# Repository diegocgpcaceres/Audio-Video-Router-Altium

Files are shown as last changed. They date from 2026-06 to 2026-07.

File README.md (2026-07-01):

# Audio/Video Router PCB Design

Diseño completo de PCB para un sistema de distribución de audio y video, desarrollado como proyecto integrador de la materia **Diseño Asistido por Computadora (DAC)** de Ingeniería Electrónica.

El proyecto abarca la captura esquemática, diseño de PCB, generación de documentación de fabricación y modelado 3D utilizando Altium Designer.

## Tecnologías y Herramientas

* **Diseño PCB:** Altium Designer
* **Modelado 3D:** Herramientas integradas de Altium Designer
* **Documentación:** BOM (Bill of Materials), planos de fabricación y ensamblado

## Estructura del Repositorio

* `/Preproyecto`: Contiene la propuesta inicial presentada para la materia, descripción del proyecto y link del fabricante.

* `/Entrega Final`: Contiene toda la documentación técnica del proyecto:

  * Archivos fuente de Altium Designer.
  * Informe técnico final.
  * Bill of Materials (BOM).
  * Datasheets de los componentes utilizados.
  * Documentación de fabricación.
  * Modelo 3D del gabinete desarrollado en OnShape.
  * Renderizados finales del PCB y del ensamblado completo.
 
## Características del Proyecto

* PCB de dos capas.
* Más de 200 componentes electrónicos.
* Componentes SMD y Through-Hole.
* Generación automática de BOM.
* Modelado tridimensional del ensamblado final.

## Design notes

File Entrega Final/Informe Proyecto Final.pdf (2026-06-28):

### Proyecto Final: DISTRIB 8x Stereo audio/video distribution router v2.1

MATERIA: Diseño Asistido por Computadora

CURSO: R1051

PROFESOR: Ing. Juan Manuel Perdomo

AYUDANTES: Ing. Cesar Angel Fuoco, Ing. Federico Giorno, Sr. Pedro Vergili

ALUMNO: Diego Cáceres

MAIL: diegocgp@frba.utn.edu.ar

I) Descripción

El DISTRIB 8x Stereo audio/video distribution router v2.1 usa elementos thru-hole y SMD junto a varios circuitos integrados para el manejo de varios tipos de señales (tanto digitales como analógicas, según el fabricante) con el propósito de entregar audio y video.

Para el diseño del PCB se usaron las dos capas permitidas (Bottom Layer y Top Layer) facilitando el diseño de las pistas, aprovechando el uso de los componentes Thru Hole y de vías.
Las dimensiones finales del PCB son 100mm X 135.5mm usando un total de 204 componentes como se detalla en el archivo Excel “R1051-Caceres-PF-BOM” generado por el mismo Altium usando la herramienta Bill Of Materials.
La diferencia entre la cantidad de componentes actual y la presentada en el Pre-Proyecto se debe a la omisión de algunos componentes, como los pulsadores, que entorpecían el diseño del PCB y que el mismo diseñador no usa sobre la placa misma, utilizar tiras de pines hembra que cuentan como unidad, y posiblemente algún fallo al contar los componentes.

El diseño del Gabinete se adaptó a las medidas del PCB conservando el largo original, proporcionado por el diseñador, manteniendo las aperturas necesarias para los puertos de comunicación y alimentación.

II) Diagrama en Bloques

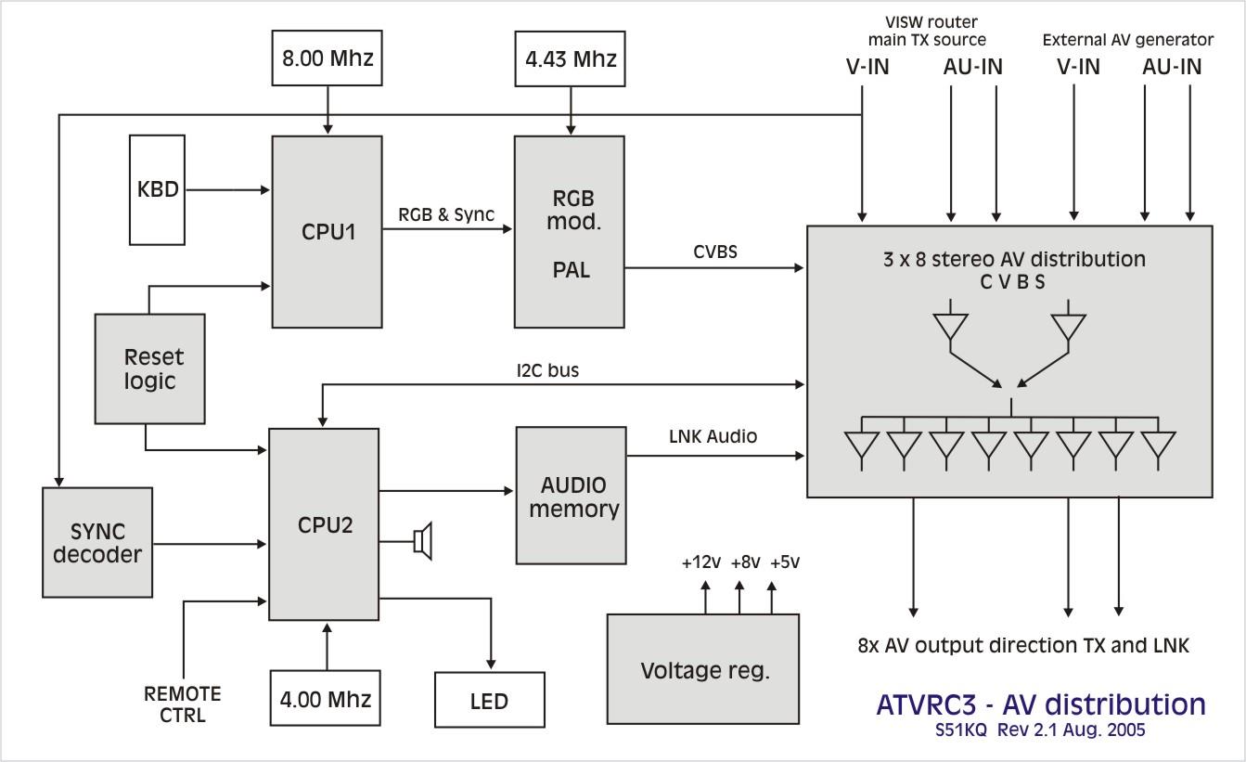
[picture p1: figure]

El diagrama en bloques presentado es el mismo proporcionado por el diseñador, siendo que varios esquemáticos del proyecto reciben su nombre debido al mismo.
En la siguiente tabla se muestra el correspondiente bloque asociado con el o los esquemáticos antes mencionados.
BLOQUES | ESQUEMÁTICOS
Voltage reg. | Power Supply
SYNC decoder | Sync Decoder
Reset logic | Audio_Video Controller
CPU1 | RGB Video Controller
CPU2 | Audio Controller
AUDIO memory | Audio Memory
RGB mod. PAL | RGB to PAL Encoder
3 x 8 stereo AV distribution | Video OUT
Left Channel Audio
Right Channel Audio

III) Diagramas de Esquemáticos

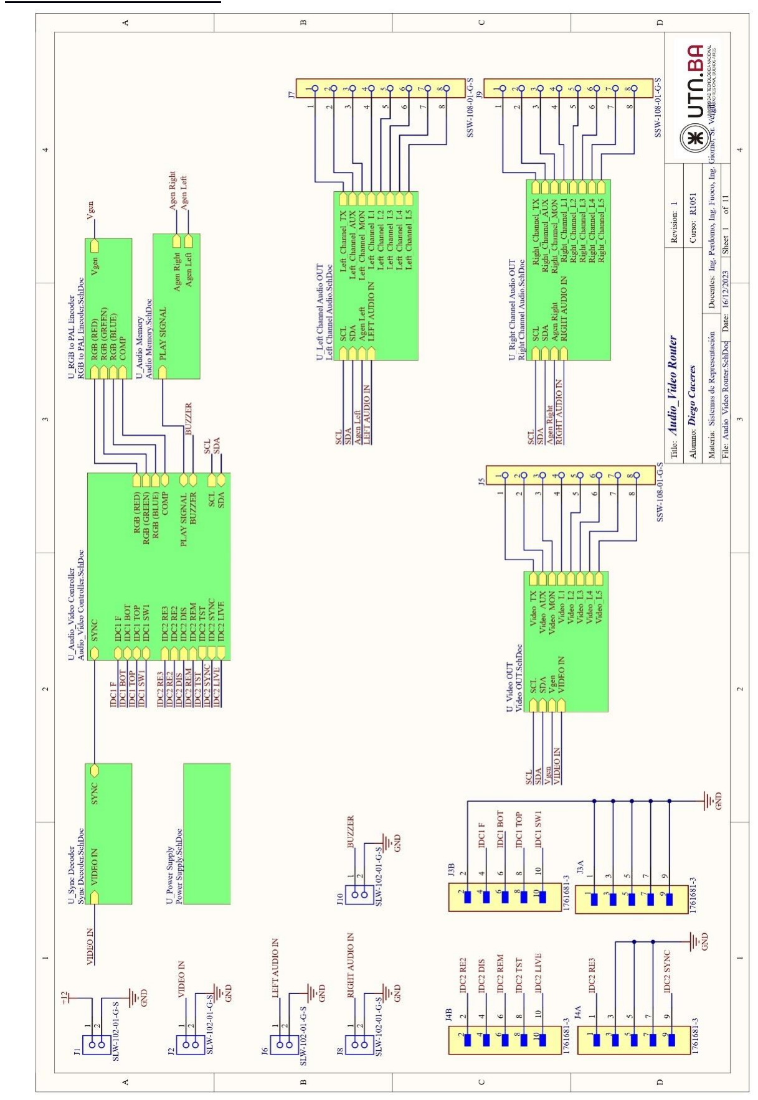
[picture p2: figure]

- Audio_Video Router

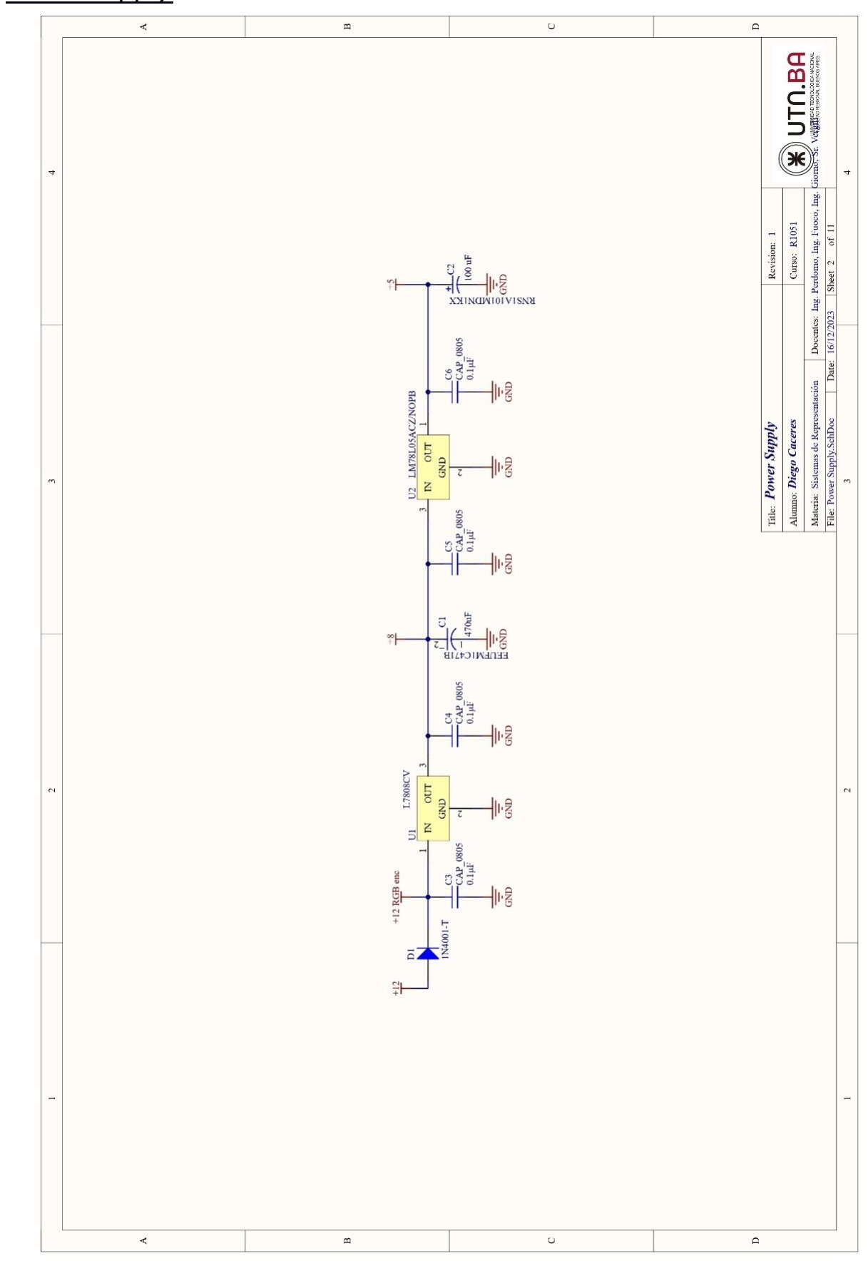
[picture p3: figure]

- Power Supply

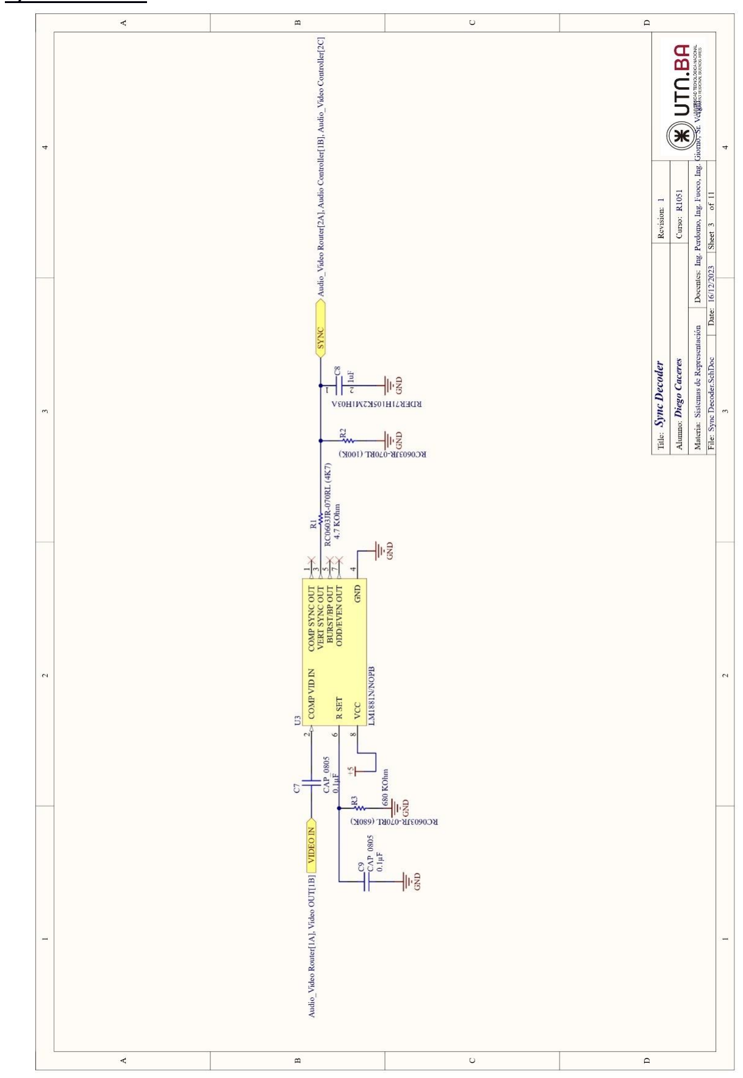
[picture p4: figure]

- Sync Decoder

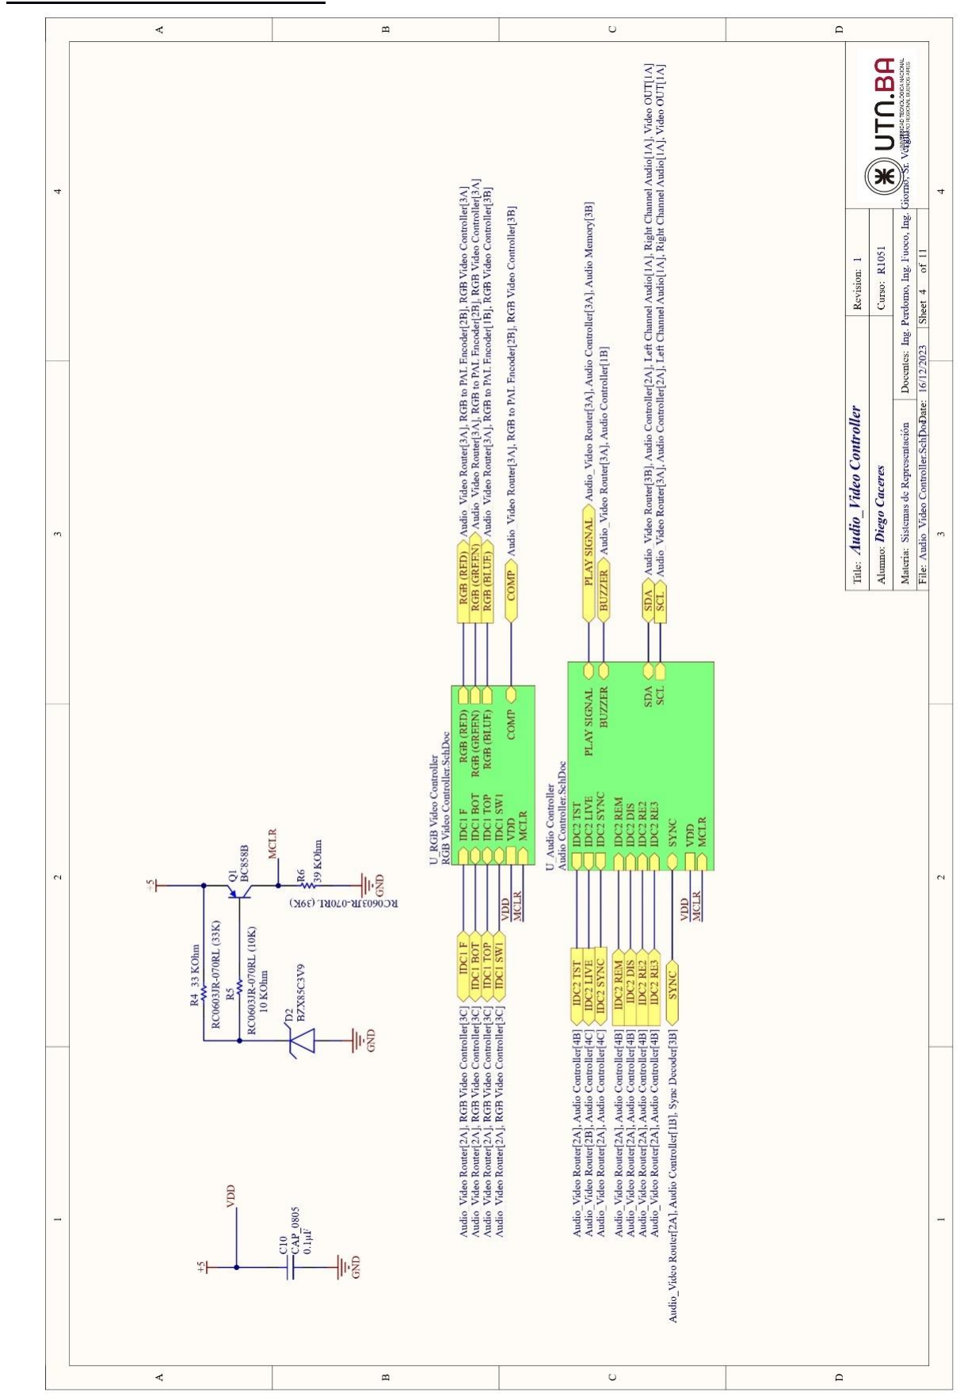
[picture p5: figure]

- Audio_Video Controller

- RGB Video Controller

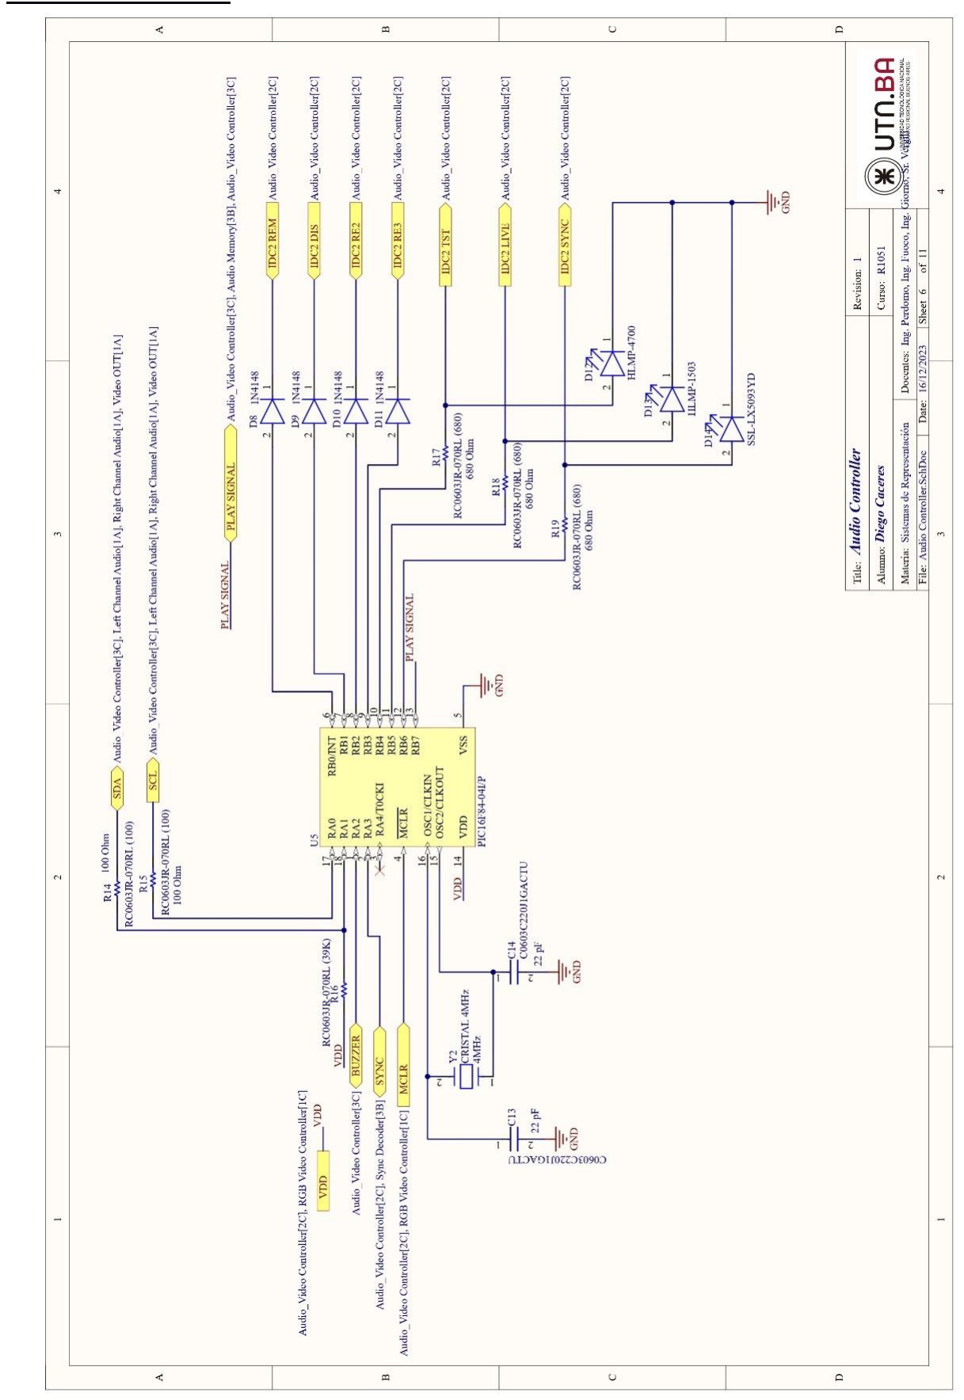
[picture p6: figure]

- Audio Controller

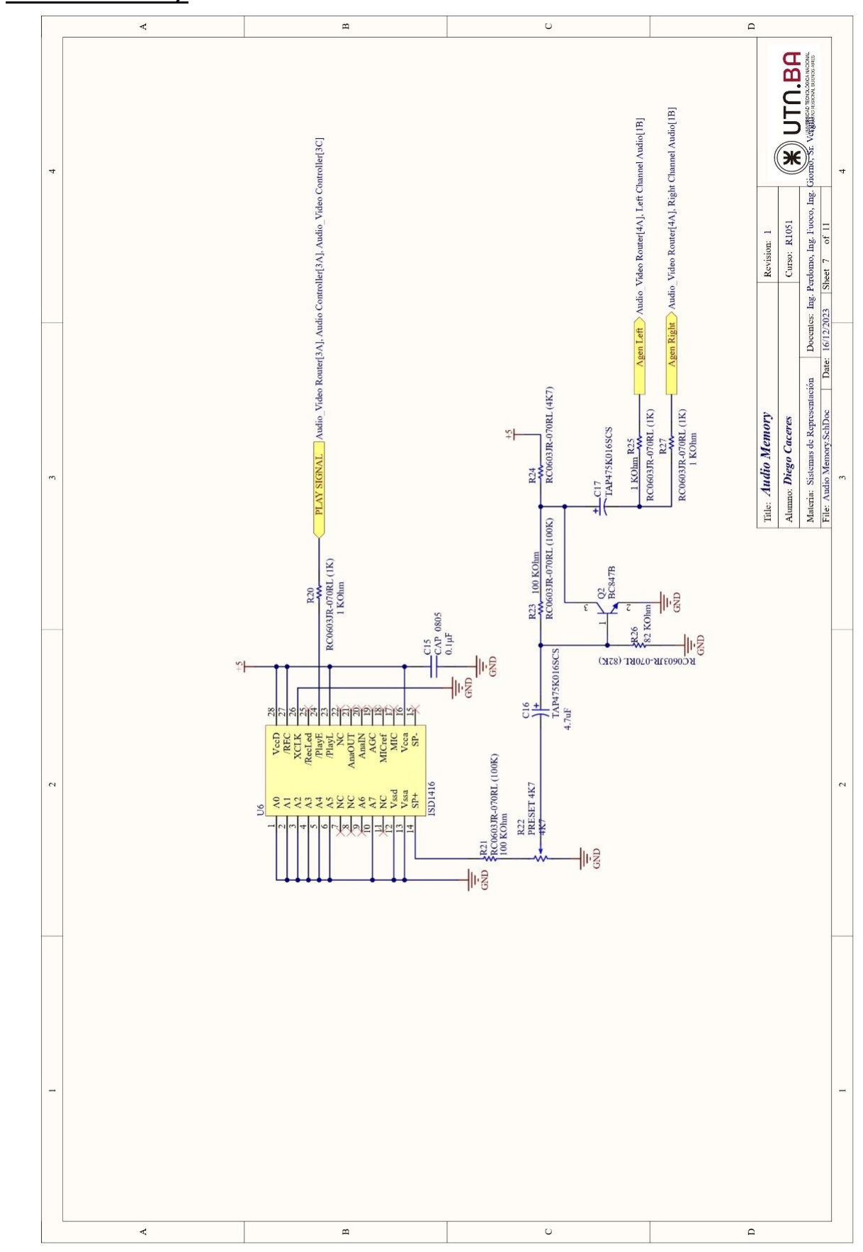
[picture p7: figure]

- Audio Memory

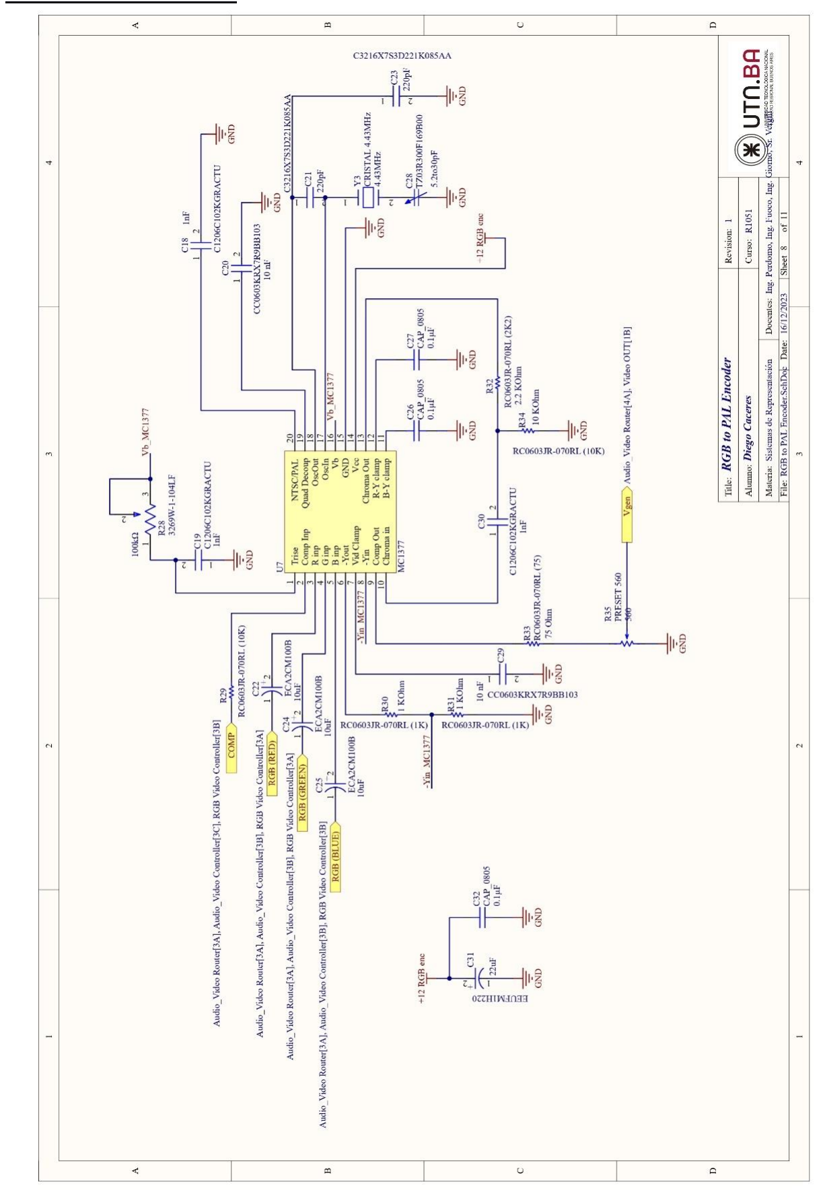
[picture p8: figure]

- RGB to PAL Encoder

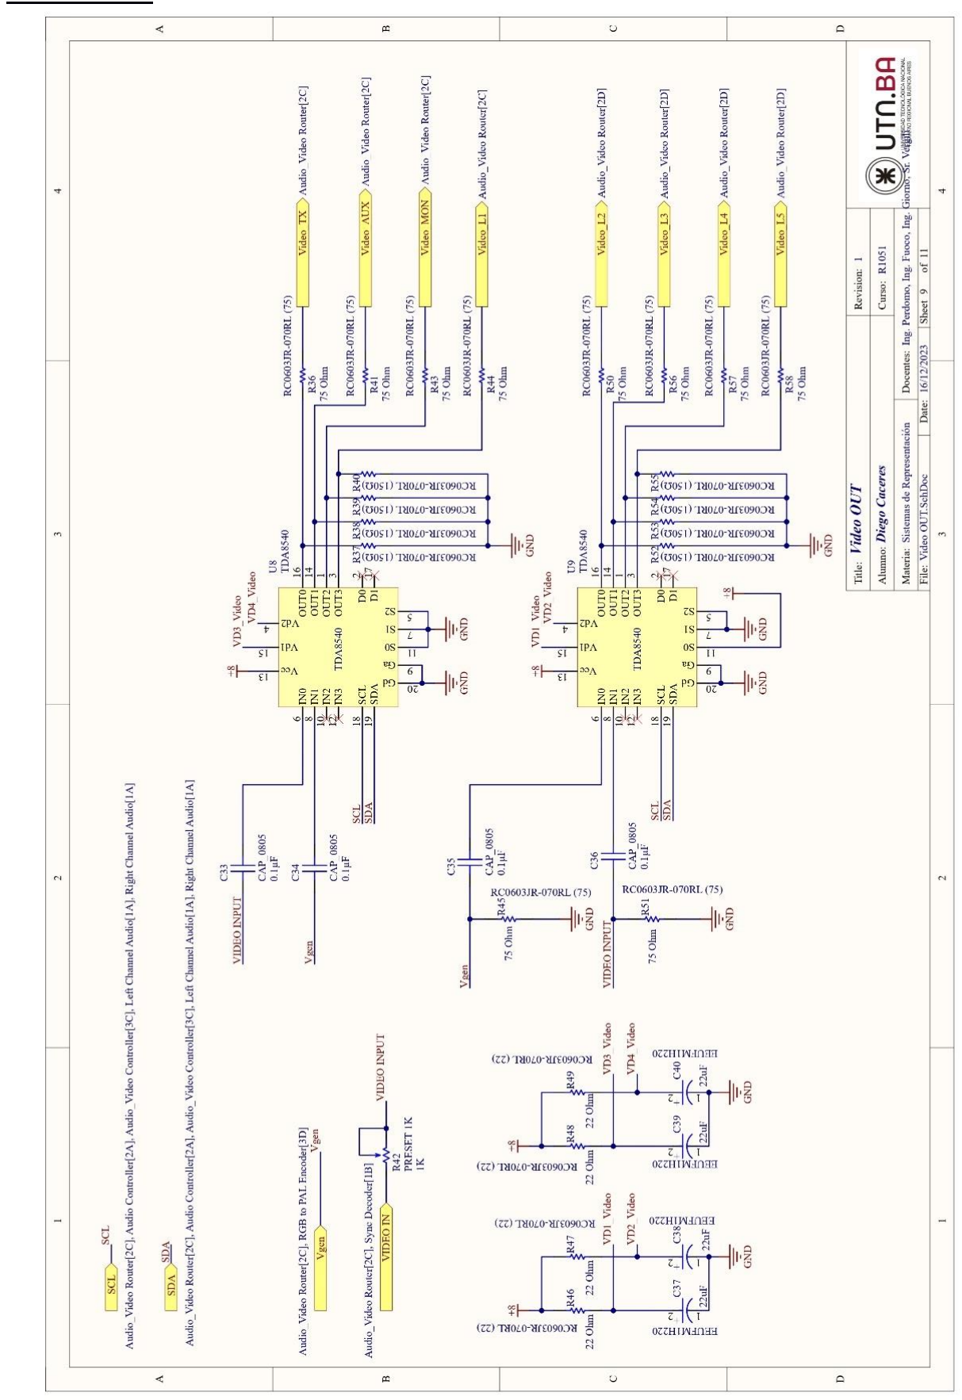
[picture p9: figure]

- Video OUT

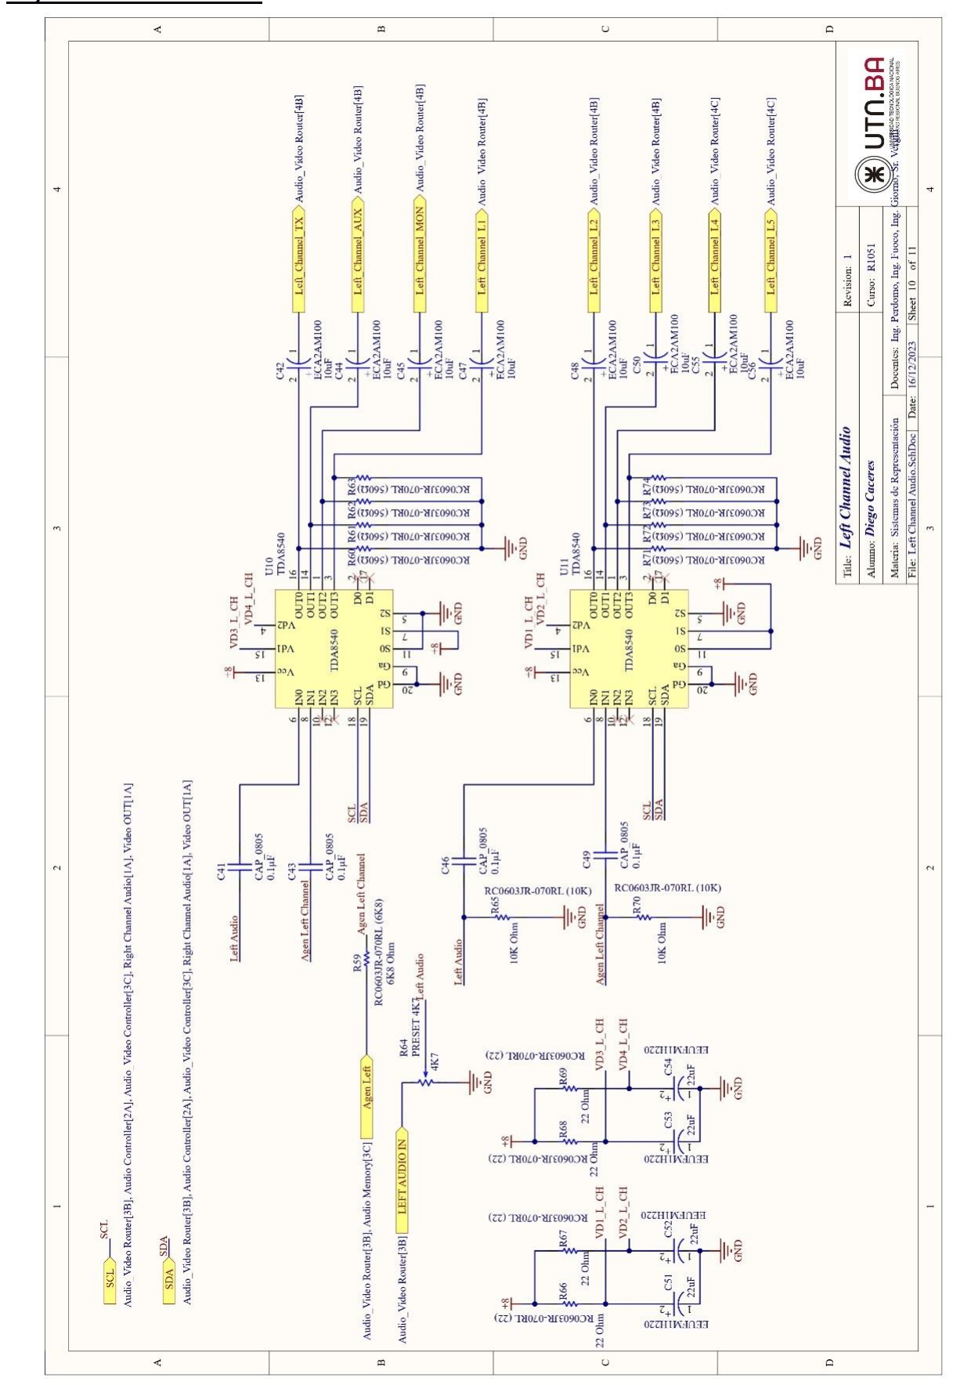
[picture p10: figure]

- Left Channel Audio

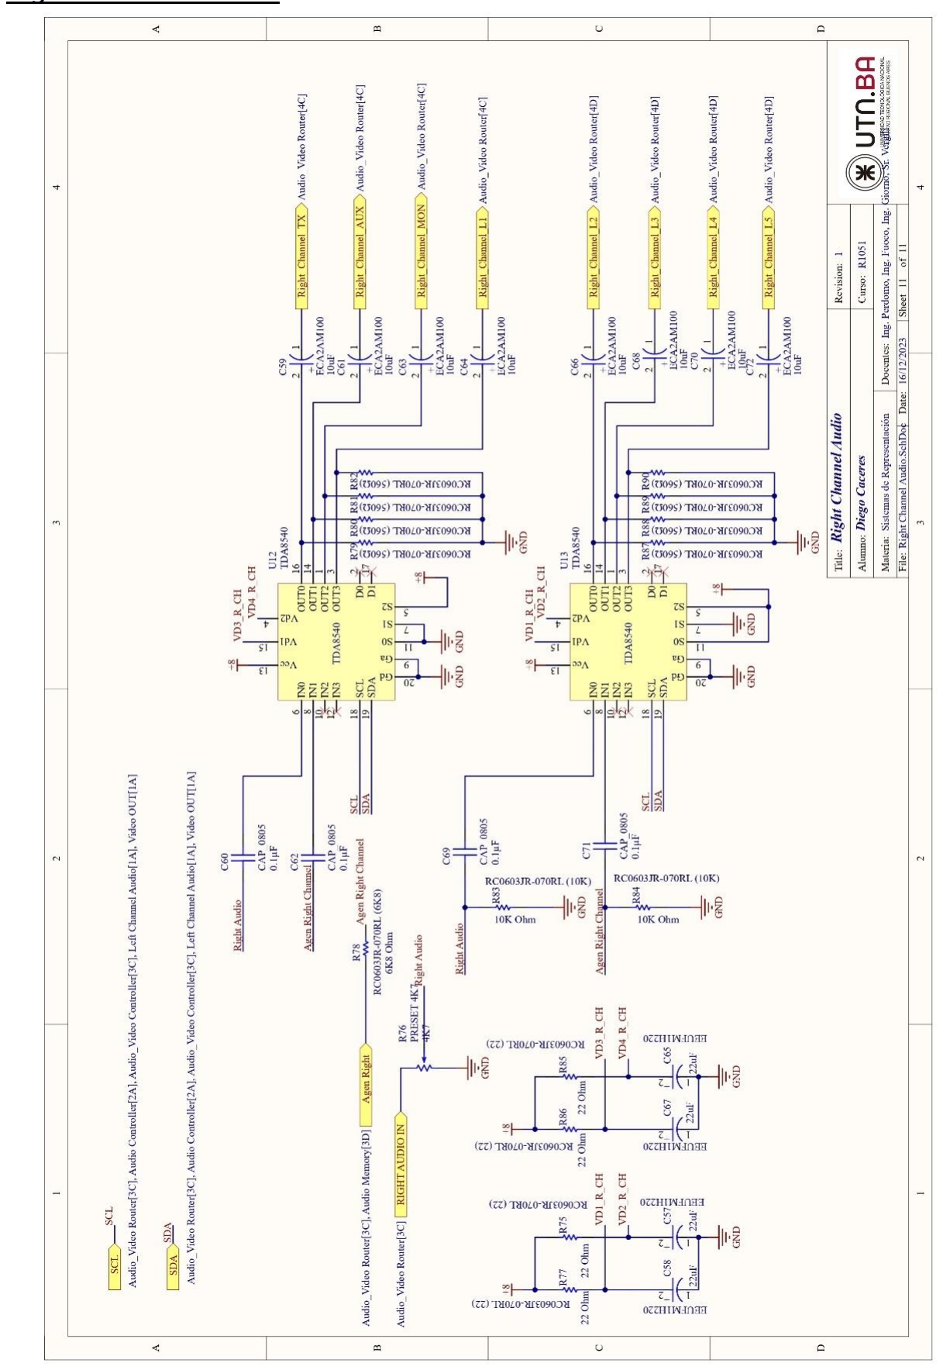
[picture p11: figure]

- Right Channel Audio

IV) Especificaciones Técnicas del PCB

Debido a que el PCB se basa totalmente en el uso de circuitos integrados es de esperar que la corriente no sea elevada.
De las hojas de datos se puede extraer que la corriente máxima que maneja el MC1377 es de 40mA, siendo está la corriente de mayor valor encontrado a lo largo de los datasheets de los integrados.

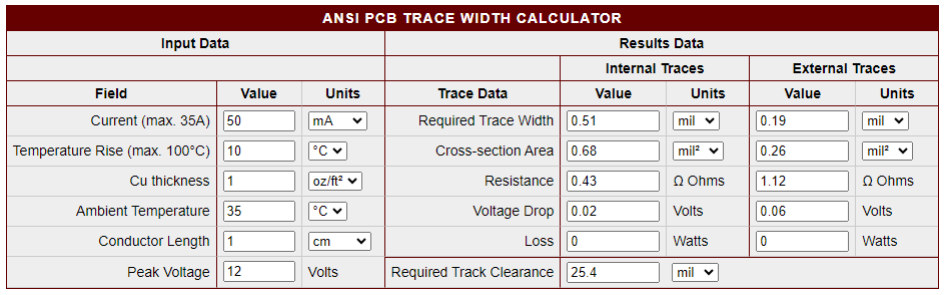
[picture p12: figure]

Para corroborar que la corriente no presenta un problema respecto a la temperatura en el diseño se recurrió a la norma IPC – 2221, entrando con una corriente de 50mA, mayor a la vista anteriormente; por lo que el criterio usado para el diseño del PCB es de 10 MILS

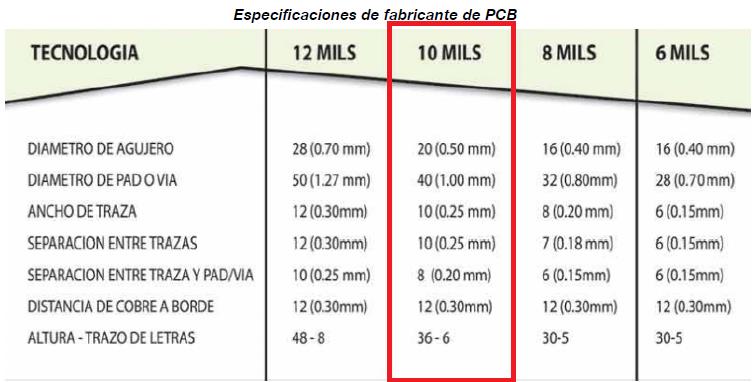
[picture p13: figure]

Que fueron introducidas en el diseño del PCB a través de las Rules que proporciona Altium.

V) Diagrama del PCB

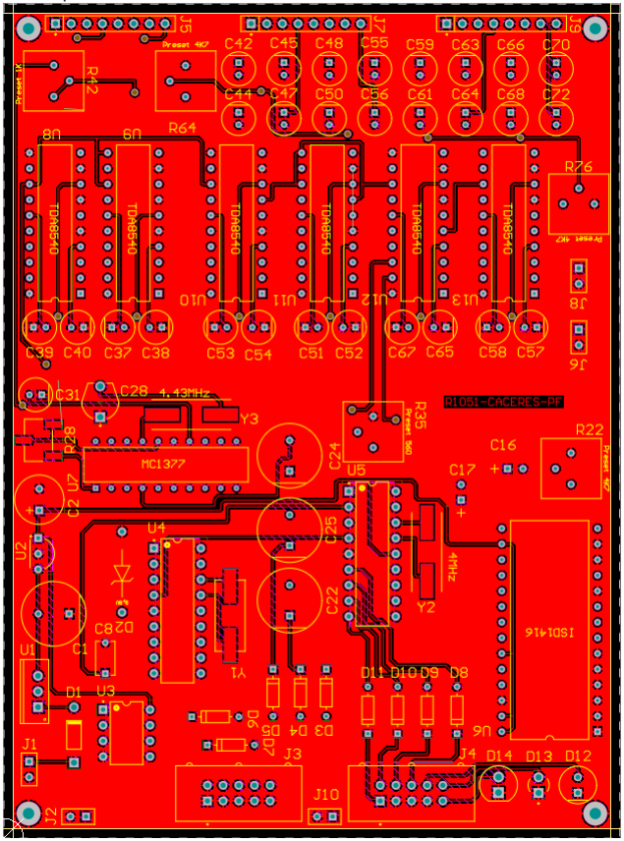
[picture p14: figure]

- Vista Top

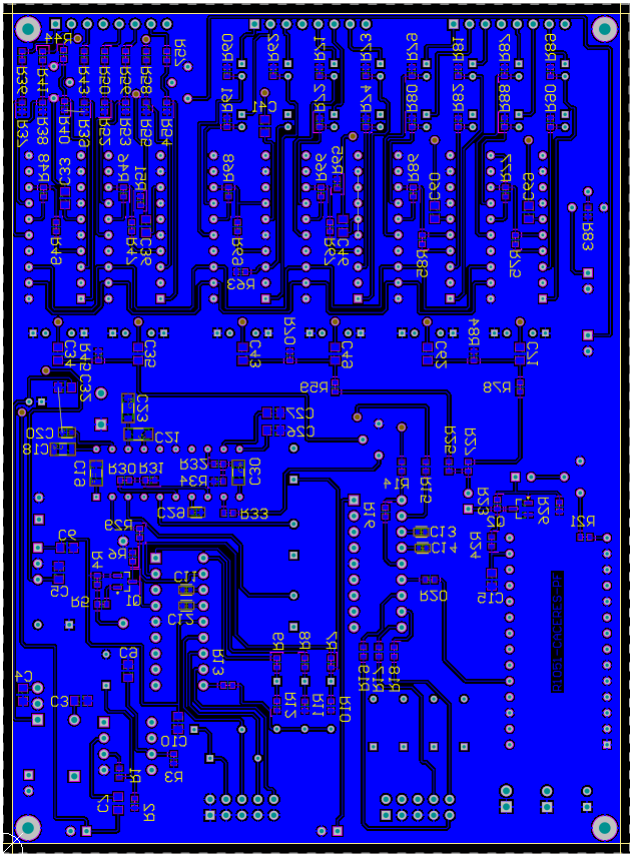
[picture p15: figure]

- Vista Bottom

VI) Render 3D del PCB Completo

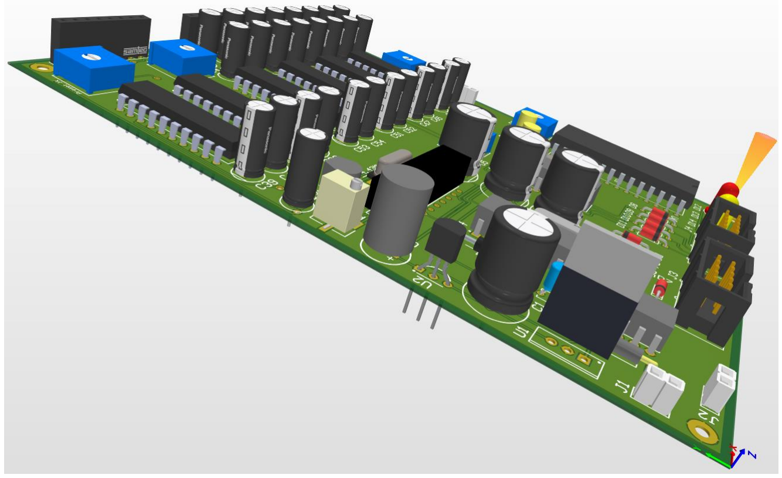
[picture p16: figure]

- Vista Isométrica

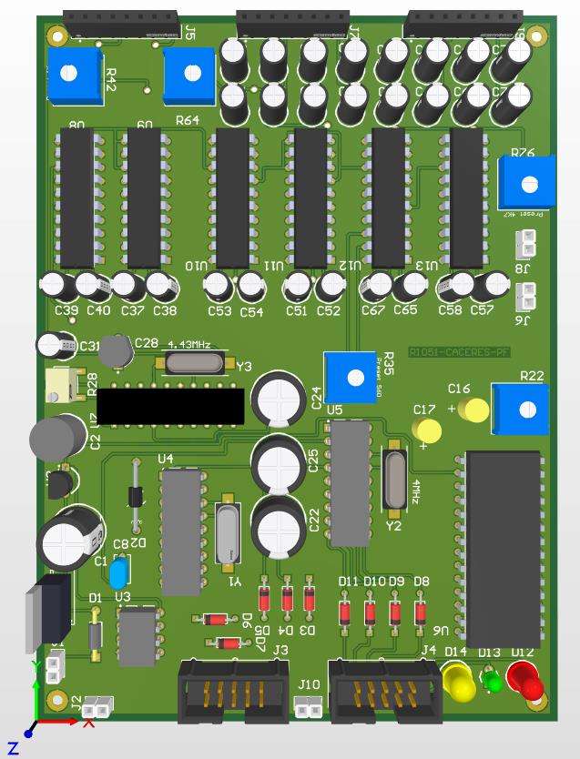
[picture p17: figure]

- Vista Superior

- Vista Inferior

VII)Lista de componentes

La entrega de este documento viene acompañado con el archivo EXCEL “R1051-Caceres-PF-BOM” generado por Altium usando la herramienta Bill Of Materials.
Igualmente se presenta en forma de imagen el contenido de dicho archivo en forma de imagen.

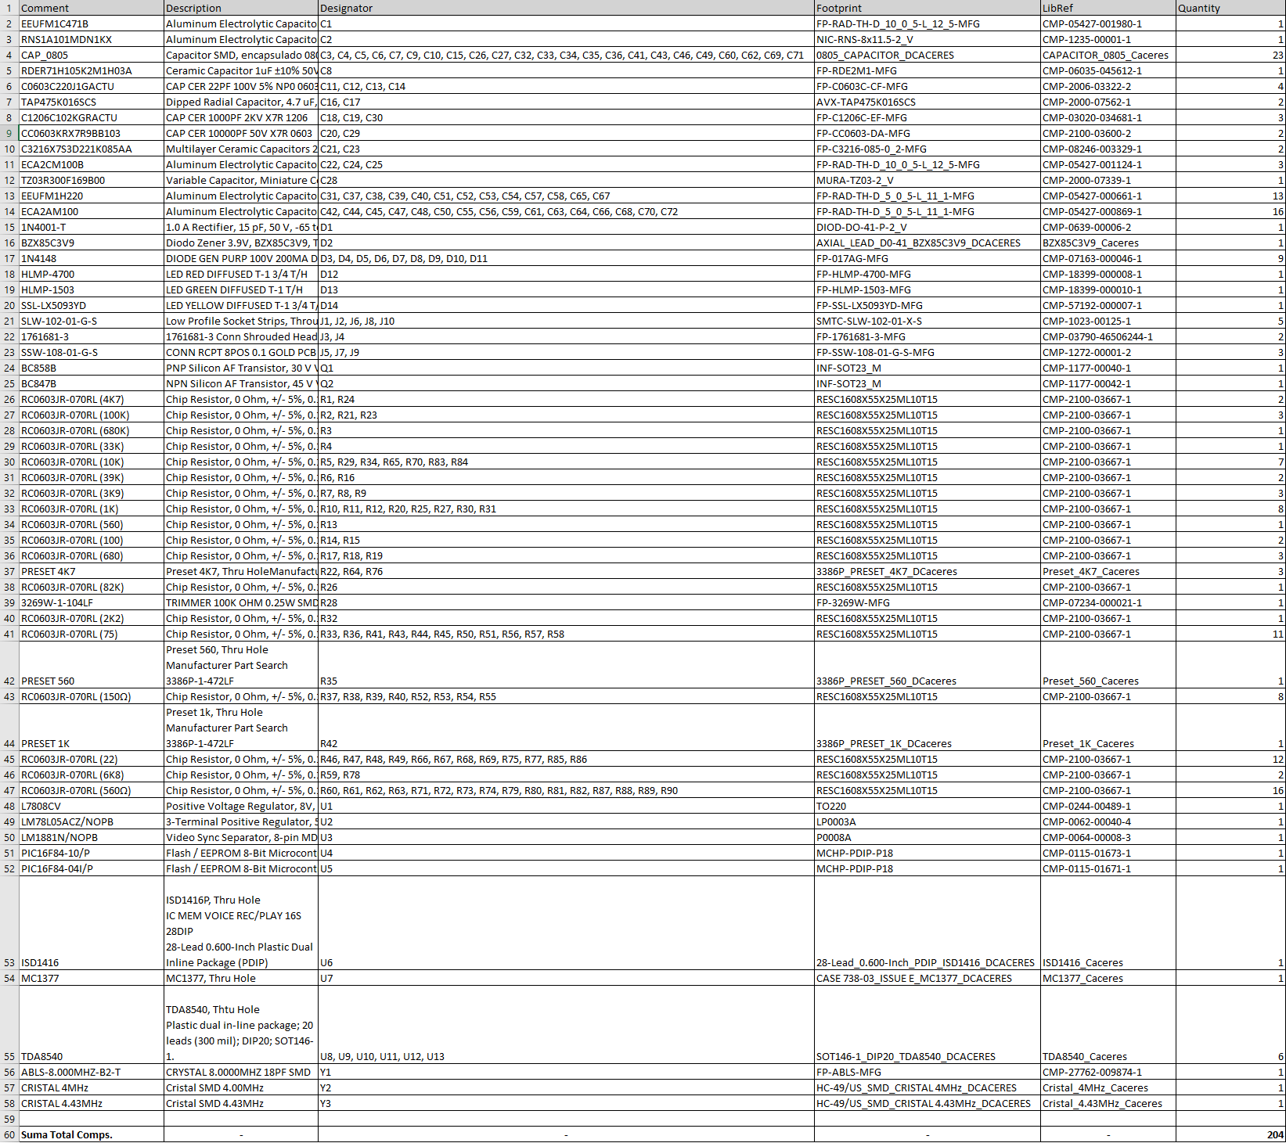
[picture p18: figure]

VIII) Especificaciones Técnicas del Gabinete

Las dimensiones del Gabinete son 200mm X 437 mm x 45mm. El mismo presenta orificios en la parte inferior para asegurar la placa usando tornillos con diámetro de 2mm, cabeza de 4mm y largo no mayor a 24mm.

El Largo del Gabinete es el mismo que el del diseñador manteniendo así las aperturas necesarias para los puertos de comunicación y la alimentación, como se muestra a continuación

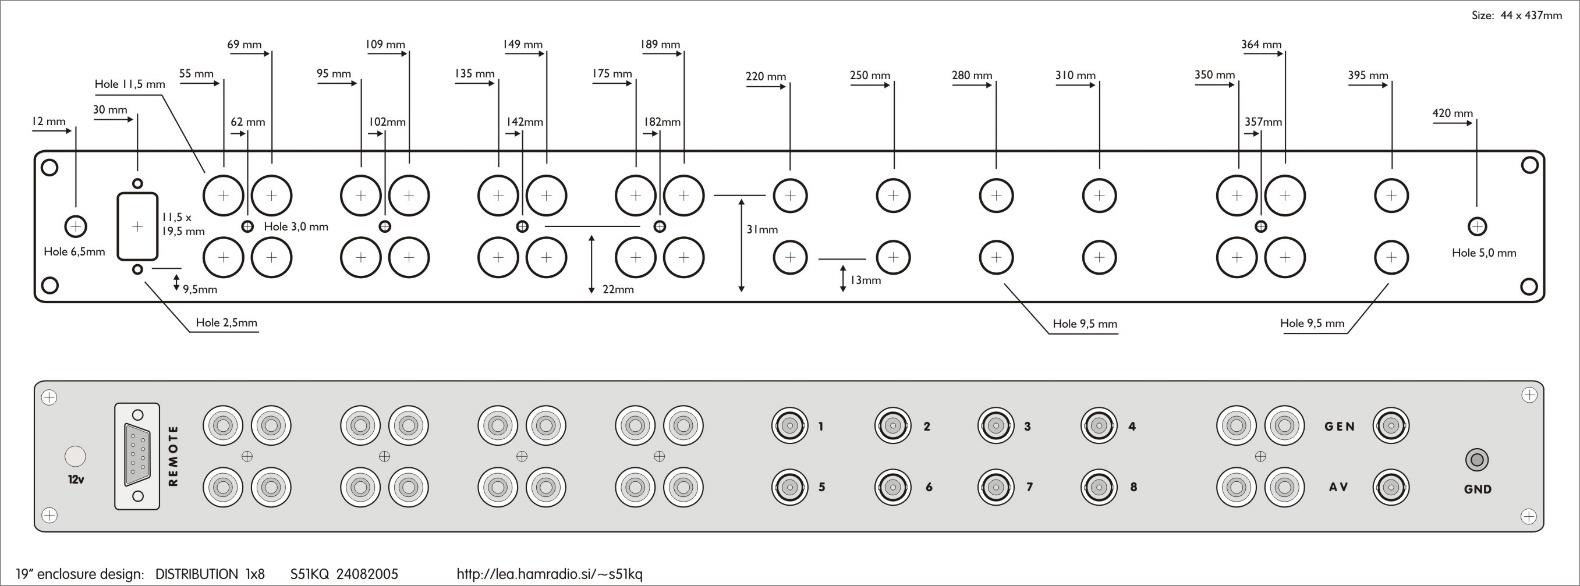
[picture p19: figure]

Las otras dos medidas, ancho y altura, fueron elegidos en función del PCB ya diseñado de forma tal que pueda entrar cómodamente y ser sujeto por los tornillos ya mencionados.

El frente del gabinete se adaptó para el uso del Buzzer, de montaje sobre Gabinete, CPI-2825-85PM cuya datasheet puede encontrarse con el resto de los componentes usados para el diseño del PCB.

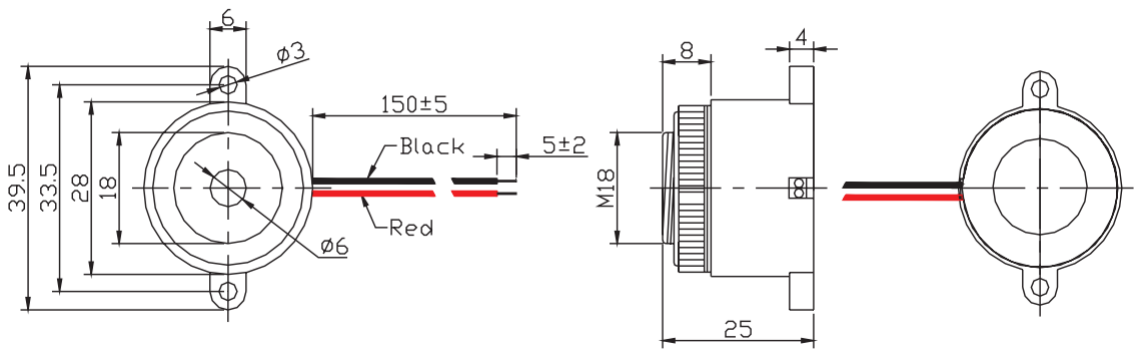
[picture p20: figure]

El modelo 3D usado en el diseño del Gabinete completo es el mismo que proporciona el fabricante

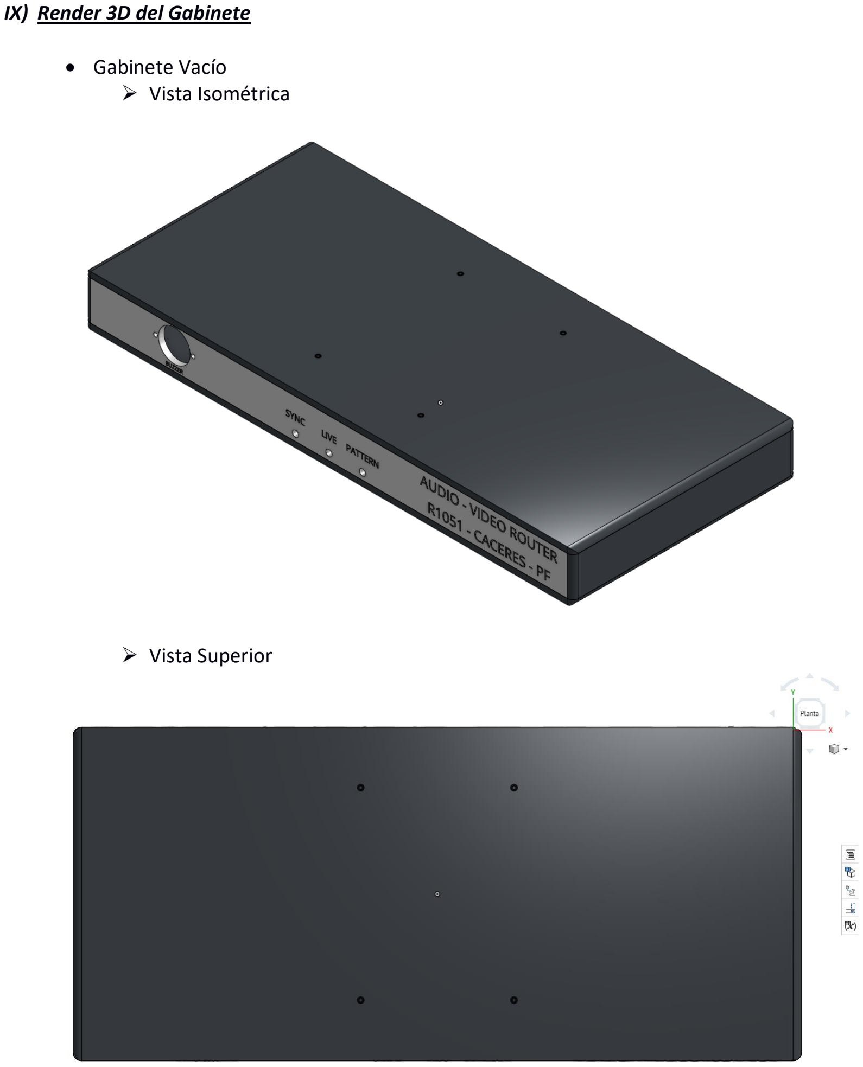
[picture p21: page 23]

IX) Render 3D del Gabinete

- Gabinete Vacío
- Vista Isométrica
- Vista Superior

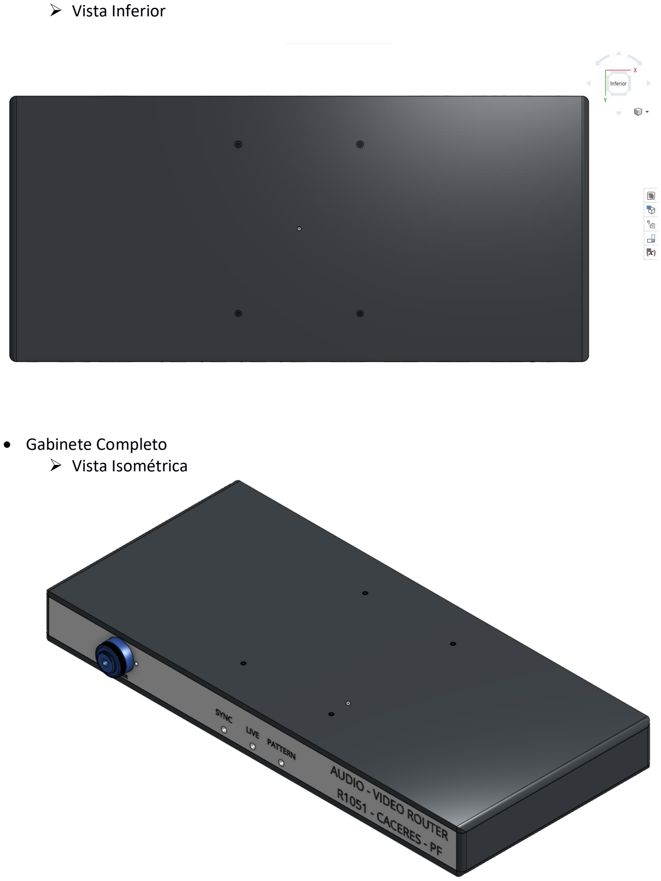
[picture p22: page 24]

- Vista Inferior
- Gabinete Completo
- Vista Isométrica

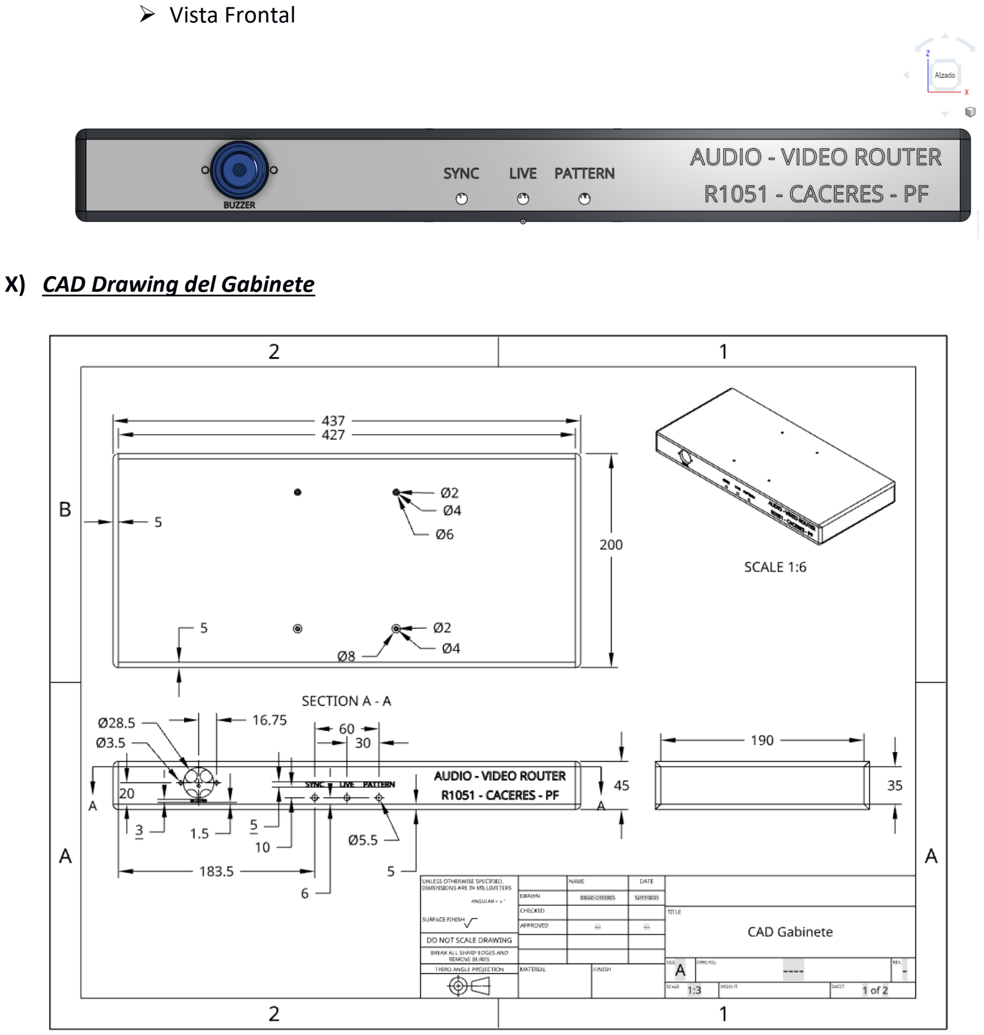
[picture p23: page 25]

- Vista Frontal
X) CAD Drawing del Gabinete

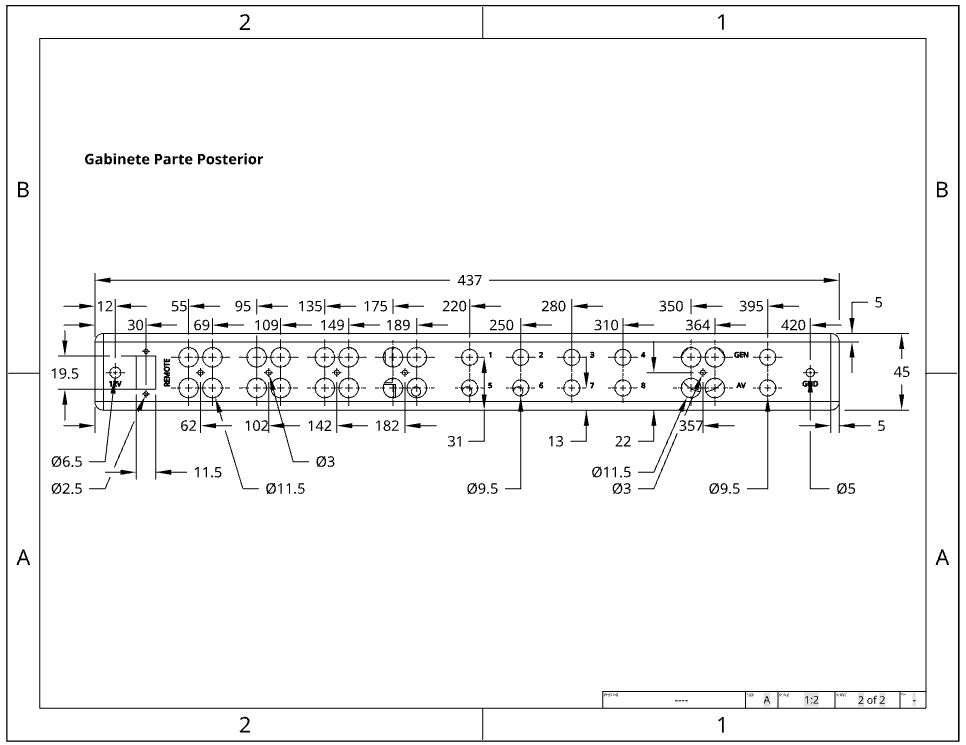
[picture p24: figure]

XI) Link De Diseñador

http://lea.hamradio.si/~s51kq/VIDEOR.HTM

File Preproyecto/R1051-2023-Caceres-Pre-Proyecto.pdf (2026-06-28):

## Pre – Proyecto: DISTRIB 8x Stereo audio/video distribution router v2.1

MATERIA: Diseño Asistido por Computadora

PROFESOR: Ing. Juan Manuel Perdomo

AYUDANTES: Ing. Cesar Angel Fuoco, Ing. Federico Giorno, Sr. Pedro Vergili

ALUMNO: Diego Cáceres

MAIL: diegocgp@frba.utn.edu.ar

I) Descripción

El DISTRIB 8x Stereo audio/video distribution router v2.1 usa elementos thru-hole y SMD junto a varios circuitos integrados para el manejo de varios tipos de señales (tanto digitales como analógicas según el fabricante) y poder entregar audio y video.

El diseño original del fabricante cuenta con una sola capa de cobre, para el proyecto se pretende usar dos capas de cobre para simplificar el diseño del PCB.

En la página del fabricante, que se deja al final de este documento, se encuentra el gabinete original con sus dimensiones que se va a usar para su posterior diseño en 3D.


II) Esquemático


Aclaraciones

En el circuito aparecen valores de resistencias denominadas 22E, 560E, 150E, etc. Las mismas hacen referencia a valores de resistencias de 22Ω, 560Ω y 150Ω respectivamente.

Los capacitores denominados únicamente como 0.1 se refiere a los capacitores SMD de 0,1 µF. Esta información se pudo obtener revisando el circuito armado del fabricante. A continuación, se deja evidencia de este, de misma manera se puede hallar más información en la pagina del fabricante que se deja al final de este documento.


De la misma forma ocurre con los capacitores cuya unidad esta denominada como 4y7 o 10y que significan 4,7µF y 10µF.


III) Lista de componentes

Componentes | Variaciones | Cantidad
Resistencias | 1 | 86
Capacitores | 3 | 79
Presets | 1 | 6
Diodos | 3 | 11
LED | 1 | 3
Transistores | 1 | 2
Cristal de Cuarzo | 3 | 3
Regulador de Tensión | 2 | 2
Circs. Integrados | 6 | 11
Pulsadores | 1 | 3
Switch | 1 | 1
Conectores IDC | 1 | 2
Pines Hembra | 1 | 56
Total | | 263

Para el listado de componentes se tuvo en consideración el canal derecho para audio que no se muestra en los esquemáticos (aclarado en el mismo).

IV) Referencia

http://lea.hamradio.si/~s51kq/VIDEOR.HTM

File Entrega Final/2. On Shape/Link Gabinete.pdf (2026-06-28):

Link del Gabinete armado en On Shape

cad.onshape.com/documents/7a710b85f99415e291056725/w/c3d240d0 2335b22a24add5ff/e/35872f51cd38a0985bce2250

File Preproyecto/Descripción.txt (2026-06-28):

Descripción
Para la entrega de pre-proyecto se requerirá que se entregue por alumno un documento que contenga una determinada información. En las siguientes listas encontrará los elementos de entrega obligatoria .

Requerimientos
Título/ Carátula del proyecto
Nombre de proyecto
Descripción del proyecto
Foto o imagen del esquemático de proyecto con la identificación clara de los componentes
Tabla que liste los tipos de componentes , su cantidad y el total de los componentes ( Nota: use el siguiente ejemplo como referencia - Ejemplo de Tabla)
Consideraciones
A la elección de esquemático para el pre-proyecto se pedirá que se cumpla con las siguiente consideraciones:

La cantidad mínima de componentes debe ser 70
La variedad mínima de componentes debe ser 8
No se debe utilizar componentes con encapsulado BGA (Ball grid array).

Entrega
La entrega se realizará Mediante el aula virtual mediante la entrega de un zip que cumpla las siguientes consideraciones:

El formato del archivo debe ser PDF.
El nombre del archivo deberá contener el ID del curso (R1051),el año, Apellido, y la leyenda "Pre-Proyecto". ( EJ; R1051-2022-Apellido-Pre-Proyecto)

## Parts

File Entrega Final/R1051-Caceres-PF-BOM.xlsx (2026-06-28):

Comment | Description | Designator | Footprint | LibRef | Quantity
EEUFM1C471B | Aluminum Electrolytic Capacitors (Radial Lead Type) 470uF ±20% 16V | C1 | FP-RAD-TH-D_10_0_5-L_12_5-MFG | CMP-05427-001980-1 | 1
RNS1A101MDN1KX | Aluminum Electrolytic Capacitor, 100 uF +/-20%, 10 V, -55 to 105 degC, 2-Pin THD, RoHS | C2 | NIC-RNS-8x11.5-2_V | CMP-1235-00001-1 | 1
CAP_0805 | Capacitor SMD, encapsulado 0805 | C3, C4, C5, C6, C7, C9, C10, C15, C26, C27, C32, C33, C34, C35, C36, C41, C43, C46, C49, C60, C62, C69, C71 | 0805_CAPACITOR_DCACERES | CAPACITOR_0805_Caceres | 23
RDER71H105K2M1H03A | Ceramic Capacitor 1uF ±10% 50V X7R Radial | C8 | FP-RDE2M1-MFG | CMP-06035-045612-1 | 1
C0603C220J1GACTU | CAP CER 22PF 100V 5% NP0 0603 | C11, C12, C13, C14 | FP-C0603C-CF-MFG | CMP-2006-03322-2 | 4
TAP475K016SCS | Dipped Radial Capacitor, 4.7 uF, +/- 10%, 16 V, -55 to 125 degC, RoHS, Bulk | C16, C17 | AVX-TAP475K016SCS | CMP-2000-07562-1 | 2
C1206C102KGRACTU | CAP CER 1000PF 2KV X7R 1206 | C18, C19, C30 | FP-C1206C-EF-MFG | CMP-03020-034681-1 | 3
CC0603KRX7R9BB103 | CAP CER 10000PF 50V X7R 0603 | C20, C29 | FP-CC0603-DA-MFG | CMP-2100-03600-2 | 2
C3216X7S3D221K085AA | Multilayer Ceramic Capacitors 220pF ±10% 2000V X7S SMD 1206 | C21, C23 | FP-C3216-085-0_2-MFG | CMP-08246-003329-1 | 2
ECA2CM100B | Aluminum Electrolytic Capacitors (Radial Lead Type) 10uF ±20% 160V | C22, C24, C25 | FP-RAD-TH-D_10_0_5-L_12_5-MFG | CMP-05427-001124-1 | 3
TZ03R300F169B00 | Variable Capacitor, Miniature Ceramic Trimmer, Green, 30 pF, -25 to 85 degC, 2-Pin THD, Bulk | C28 | MURA-TZ03-2_V | CMP-2000-07339-1 | 1
EEUFM1H220 | Aluminum Electrolytic Capacitors (Radial Lead Type) 22uF ±20% 50V | C31, C37, C38, C39, C40, C51, C52, C53, C54, C57, C58, C65, C67 | FP-RAD-TH-D_5_0_5-L_11_1-MFG | CMP-05427-000661-1 | 13
ECA2AM100 | Aluminum Electrolytic Capacitors (Radial Lead Type) 10uF ±20% 100V | C42, C44, C45, C47, C48, C50, C55, C56, C59, C61, C63, C64, C66, C68, C70, C72 | FP-RAD-TH-D_5_0_5-L_11_1-MFG | CMP-05427-000869-1 | 16
1N4001-T | 1.0 A Rectifier, 15 pF, 50 V, -65 to 150 degC, 2-Pin DO-41 Plastic, RoHS, Tape and Reel | D1 | DIOD-DO-41-P-2_V | CMP-0639-00006-2 | 1
BZX85C3V9 | Diodo Zener 3.9V, BZX85C3V9, Thru Hole | D2 | AXIAL_LEAD_D0-41_BZX85C3V9_DCACERES | BZX85C3V9_Caceres | 1
1N4148 | DIODE GEN PURP 100V 200MA DO35 | D3, D4, D5, D6, D7, D8, D9, D10, D11 | FP-017AG-MFG | CMP-07163-000046-1 | 9
HLMP-4700 | LED RED DIFFUSED T-1 3/4 T/H | D12 | FP-HLMP-4700-MFG | CMP-18399-000008-1 | 1
HLMP-1503 | LED GREEN DIFFUSED T-1 T/H | D13 | FP-HLMP-1503-MFG | CMP-18399-000010-1 | 1
SSL-LX5093YD | LED YELLOW DIFFUSED T-1 3/4 T/H | D14 | FP-SSL-LX5093YD-MFG | CMP-57192-000007-1 | 1
SLW-102-01-G-S | Low Profile Socket Strips, Through-hole, Vertical, -55 to 125 degC, 2.54 mm Pitch, 2-Pin, Female, RoHS | J1, J2, J6, J8, J10 | SMTC-SLW-102-01-X-S | CMP-1023-00125-1 | 5
1761681-3 | 1761681-3 Conn Shrouded Header (4 Sides) HDR 10 POS 2.54mm Solder ST Top Entry Thru-Hole Tray | J3, J4 | FP-1761681-3-MFG | CMP-03790-46506244-1 | 2
SSW-108-01-G-S | CONN RCPT 8POS 0.1 GOLD PCB | J5, J7, J9 | FP-SSW-108-01-G-S-MFG | CMP-1272-00001-2 | 3
BC858B | PNP Silicon AF Transistor, 30 V VCEO, 100 mA IC, SOT23, Reel, Green | Q1 | INF-SOT23_M | CMP-1177-00040-1 | 1
BC847B | NPN Silicon AF Transistor, 45 V VCEO, 100 mA IC, SOT23, Reel, Green | Q2 | INF-SOT23_M | CMP-1177-00042-1 | 1
RC0603JR-070RL (4K7) | Chip Resistor, 0 Ohm, +/- 5%, 0.1 W, -55 to 155 degC, 0603 (1608 Metric), RoHS, Tape and Reel | R1, R24 | RESC1608X55X25ML10T15 | CMP-2100-03667-1 | 2
RC0603JR-070RL (100K) | Chip Resistor, 0 Ohm, +/- 5%, 0.1 W, -55 to 155 degC, 0603 (1608 Metric), RoHS, Tape and Reel | R2, R21, R23 | RESC1608X55X25ML10T15 | CMP-2100-03667-1 | 3
RC0603JR-070RL (680K) | Chip Resistor, 0 Ohm, +/- 5%, 0.1 W, -55 to 155 degC, 0603 (1608 Metric), RoHS, Tape and Reel | R3 | RESC1608X55X25ML10T15 | CMP-2100-03667-1 | 1
RC0603JR-070RL (33K) | Chip Resistor, 0 Ohm, +/- 5%, 0.1 W, -55 to 155 degC, 0603 (1608 Metric), RoHS, Tape and Reel | R4 | RESC1608X55X25ML10T15 | CMP-2100-03667-1 | 1
RC0603JR-070RL (10K) | Chip Resistor, 0 Ohm, +/- 5%, 0.1 W, -55 to 155 degC, 0603 (1608 Metric), RoHS, Tape and Reel | R5, R29, R34, R65, R70, R83, R84 | RESC1608X55X25ML10T15 | CMP-2100-03667-1 | 7
RC0603JR-070RL (39K) | Chip Resistor, 0 Ohm, +/- 5%, 0.1 W, -55 to 155 degC, 0603 (1608 Metric), RoHS, Tape and Reel | R6, R16 | RESC1608X55X25ML10T15 | CMP-2100-03667-1 | 2
RC0603JR-070RL (3K9) | Chip Resistor, 0 Ohm, +/- 5%, 0.1 W, -55 to 155 degC, 0603 (1608 Metric), RoHS, Tape and Reel | R7, R8, R9 | RESC1608X55X25ML10T15 | CMP-2100-03667-1 | 3
RC0603JR-070RL (1K) | Chip Resistor, 0 Ohm, +/- 5%, 0.1 W, -55 to 155 degC, 0603 (1608 Metric), RoHS, Tape and Reel | R10, R11, R12, R20, R25, R27, R30, R31 | RESC1608X55X25ML10T15 | CMP-2100-03667-1 | 8
RC0603JR-070RL (560) | Chip Resistor, 0 Ohm, +/- 5%, 0.1 W, -55 to 155 degC, 0603 (1608 Metric), RoHS, Tape and Reel | R13 | RESC1608X55X25ML10T15 | CMP-2100-03667-1 | 1
RC0603JR-070RL (100) | Chip Resistor, 0 Ohm, +/- 5%, 0.1 W, -55 to 155 degC, 0603 (1608 Metric), RoHS, Tape and Reel | R14, R15 | RESC1608X55X25ML10T15 | CMP-2100-03667-1 | 2
RC0603JR-070RL (680) | Chip Resistor, 0 Ohm, +/- 5%, 0.1 W, -55 to 155 degC, 0603 (1608 Metric), RoHS, Tape and Reel | R17, R18, R19 | RESC1608X55X25ML10T15 | CMP-2100-03667-1 | 3
PRESET 4K7 | Preset 4K7, Thru HoleManufacturer Part Search 3386P-1-472LF | R22, R64, R76 | 3386P_PRESET_4K7_DCaceres | Preset_4K7_Caceres | 3
RC0603JR-070RL (82K) | Chip Resistor, 0 Ohm, +/- 5%, 0.1 W, -55 to 155 degC, 0603 (1608 Metric), RoHS, Tape and Reel | R26 | RESC1608X55X25ML10T15 | CMP-2100-03667-1 | 1
3269W-1-104LF | TRIMMER 100K OHM 0.25W SMD | R28 | FP-3269W-MFG | CMP-07234-000021-1 | 1
RC0603JR-070RL (2K2) | Chip Resistor, 0 Ohm, +/- 5%, 0.1 W, -55 to 155 degC, 0603 (1608 Metric), RoHS, Tape and Reel | R32 | RESC1608X55X25ML10T15 | CMP-2100-03667-1 | 1
RC0603JR-070RL (75) | Chip Resistor, 0 Ohm, +/- 5%, 0.1 W, -55 to 155 degC, 0603 (1608 Metric), RoHS, Tape and Reel | R33, R36, R41, R43, R44, R45, R50, R51, R56, R57, R58 | RESC1608X55X25ML10T15 | CMP-2100-03667-1 | 11
PRESET 560 | Preset 560, Thru Hole Manufacturer Part Search 3386P-1-472LF | R35 | 3386P_PRESET_560_DCaceres | Preset_560_Caceres | 1
RC0603JR-070RL (150Ω) | Chip Resistor, 0 Ohm, +/- 5%, 0.1 W, -55 to 155 degC, 0603 (1608 Metric), RoHS, Tape and Reel | R37, R38, R39, R40, R52, R53, R54, R55 | RESC1608X55X25ML10T15 | CMP-2100-03667-1 | 8
PRESET 1K | Preset 1k, Thru Hole Manufacturer Part Search 3386P-1-472LF | R42 | 3386P_PRESET_1K_DCaceres | Preset_1K_Caceres | 1
RC0603JR-070RL (22) | Chip Resistor, 0 Ohm, +/- 5%, 0.1 W, -55 to 155 degC, 0603 (1608 Metric), RoHS, Tape and Reel | R46, R47, R48, R49, R66, R67, R68, R69, R75, R77, R85, R86 | RESC1608X55X25ML10T15 | CMP-2100-03667-1 | 12
RC0603JR-070RL (6K8) | Chip Resistor, 0 Ohm, +/- 5%, 0.1 W, -55 to 155 degC, 0603 (1608 Metric), RoHS, Tape and Reel | R59, R78 | RESC1608X55X25ML10T15 | CMP-2100-03667-1 | 2
RC0603JR-070RL (560Ω) | Chip Resistor, 0 Ohm, +/- 5%, 0.1 W, -55 to 155 degC, 0603 (1608 Metric), RoHS, Tape and Reel | R60, R61, R62, R63, R71, R72, R73, R74, R79, R80, R81, R82, R87, R88, R89, R90 | RESC1608X55X25ML10T15 | CMP-2100-03667-1 | 16
L7808CV | Positive Voltage Regulator, 8V, 3-Pin TO-220 | U1 | TO220 | CMP-0244-00489-1 | 1
LM78L05ACZ/NOPB | 3-Terminal Positive Regulator, 5 Vout, 3-pin TO-92, Pb-Free | U2 | LP0003A | CMP-0062-00040-4 | 1
LM1881N/NOPB | Video Sync Separator, 8-pin MDIP, Pb-Free | U3 | P0008A | CMP-0064-00008-3 | 1
PIC16F84-10/P | Flash / EEPROM 8-Bit Microcontroller, 10 MHz, 13 I/O, 0 to 70 degC, 18-pin PDIP (P18), Tube | U4 | MCHP-PDIP-P18 | CMP-0115-01673-1 | 1
PIC16F84-04I/P | Flash / EEPROM 8-Bit Microcontroller, 4 MHz, 13 I/O, -40 to 85 degC, 18-pin PDIP (P18), Tube | U5 | MCHP-PDIP-P18 | CMP-0115-01671-1 | 1
ISD1416 | ISD1416P, Thru Hole IC MEM VOICE REC/PLAY 16S 28DIP 28-Lead 0.600-Inch Plastic Dual Inline Package (PDIP) | U6 | 28-Lead_0.600-Inch_PDIP_ISD1416_DCACERES | ISD1416_Caceres | 1
MC1377 | MC1377, Thru Hole | U7 | CASE 738-03_ISSUE E_MC1377_DCACERES | MC1377_Caceres | 1
TDA8540 | TDA8540, Thtu Hole Plastic dual in-line package; 20 leads (300 mil); DIP20; SOT146-1. | U8, U9, U10, U11, U12, U13 | SOT146-1_DIP20_TDA8540_DCACERES | TDA8540_Caceres | 6
ABLS-8.000MHZ-B2-T | CRYSTAL 8.0000MHZ 18PF SMD | Y1 | FP-ABLS-MFG | CMP-27762-009874-1 | 1
CRISTAL 4MHz | Cristal SMD 4.00MHz | Y2 | HC-49/US_SMD_CRISTAL 4MHz_DCACERES | Cristal_4MHz_Caceres | 1
CRISTAL 4.43MHz | Cristal SMD 4.43MHz | Y3 | HC-49/US_SMD_CRISTAL 4.43MHz_DCACERES | Cristal_4.43MHz_Caceres | 1
Suma Total Comps. | - | - | - | - | 204

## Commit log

2026-06-28 Diseño de PCB en Altium realizado para la materia Diseño Asistido por Computadora
    [Audio Controller.SchDoc, Audio Memory.SchDoc, Audio_Video Controller.SchDoc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]
2026-06-30 Add README for Audio/Video Router PCB Design project
    Added a complete README for the Audio/Video Router PCB Design project, detailing project scope, technologies, repository structure, and project features.
